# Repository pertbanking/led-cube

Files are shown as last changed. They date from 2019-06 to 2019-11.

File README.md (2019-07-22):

# led-cube
This is the repository for the code, schematics, and boards of an 8x8x8 LED cube.

## Folder hierarchy

Folder / File            | Purpose                                                          
------------------------- | ----------------------------------------------------------------
`arduino_serial_client/`  | Arduino code.
`pcb/`                    | Contains PCB schematics and boards for the multiplexing circuit. 
&nbsp;&nbsp;&nbsp;&nbsp;`/master pcb/`        | The decoder selector circuit
&nbsp;&nbsp;&nbsp;&nbsp;`/slave pcb/`         | The D Flip-Flop circuit for each row of LEDs
&nbsp;&nbsp;&nbsp;&nbsp;`/datasheets/`        | Datasheets for the ICs in the circuit
`pi/`                     | Contains all animation code. Build the project in this directory with its `CMakeLists.txt` file (see below). So named because I recommend you run this on a Raspberry Pi.
&nbsp;&nbsp;&nbsp;&nbsp;`/serial/`            | The standalone `serial` library (see below).
&nbsp;&nbsp;&nbsp;&nbsp;`/src/`               | Code source.
&nbsp;&nbsp;&nbsp;&nbsp;&nbsp;&nbsp;&nbsp;&nbsp;`/LEDCube.h`     | Represents the cube. Sends data to the Arduino through `serial`. Contains many helpful drawing functions. 
&nbsp;&nbsp;&nbsp;&nbsp;&nbsp;&nbsp;&nbsp;&nbsp;`/Animation.h`   | Header file for the generic animation. Extend this class to make your own animation!
&nbsp;&nbsp;&nbsp;&nbsp;&nbsp;&nbsp;&nbsp;&nbsp;`/animations/`   | Contains animation files. Each file represents a different animation.
&nbsp;&nbsp;&nbsp;&nbsp;&nbsp;&nbsp;&nbsp;&nbsp;`/main.cpp`      | An example client program. It is highly recommended you specialize this program instead of making your own.

More details coming soon.

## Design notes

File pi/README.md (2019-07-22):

# Animator

These classes represent the LED cube and its animations. They are meant to be run on a system (I used a Raspberry Pi) with an Arduino connected to its USB port. 

## Build

### Executable
```
$ mkdir build && cd build
$ cmake ..
$ make
```

### Documentation
```
$ doxygen
````

## Run
In the `pi` directory,
```
$ ./animate [name of the Aruduino's USB port]
```
(assuming you haven't changed the name of the executable in the CMake folder)

The default value of the USB port is `/dev/ttyUSB0`, but you may have to specify it in the command line. 

## Making your own animations
Coming soon.

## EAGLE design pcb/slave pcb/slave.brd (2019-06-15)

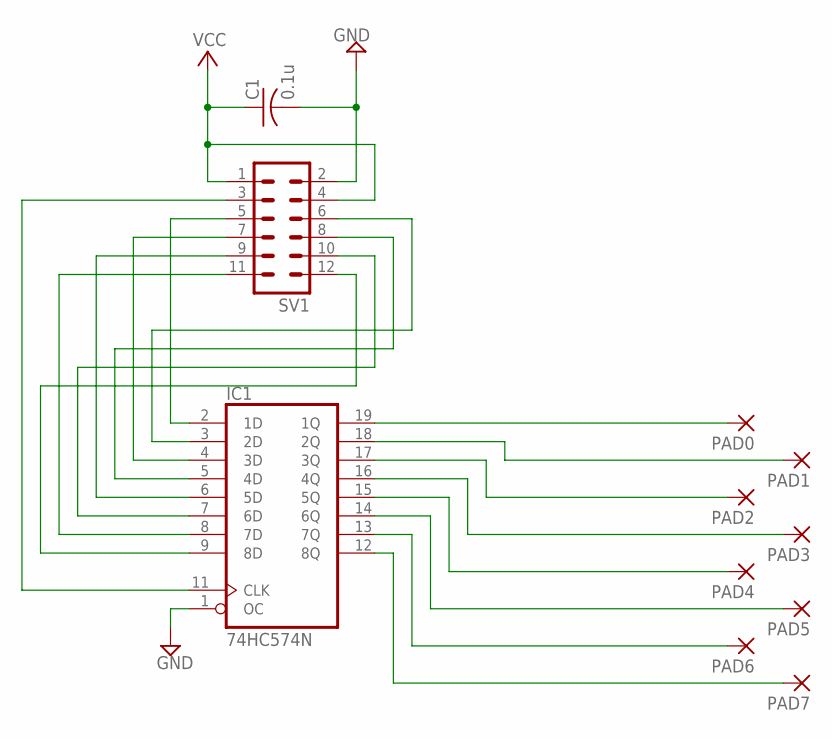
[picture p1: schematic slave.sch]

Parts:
C1: 0.1u; C0805
IC1: 74HC574N; DIL20
PAD0, PAD1, PAD2, PAD3, PAD4, PAD5, PAD6, PAD7: 2,54/0,8
SV1: MA06-2

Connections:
CLK: IC1.11 (CLK), SV1.3
GND: C1.2, IC1.1 (OC), IC1.10 (GND), SV1.2
IN0: IC1.2 (1D), SV1.5
IN1: IC1.3 (2D), SV1.6
IN2: IC1.4 (3D), SV1.7
IN3: IC1.5 (4D), SV1.8
IN4: IC1.6 (5D), SV1.9
IN5: IC1.7 (6D), SV1.10
IN6: IC1.8 (7D), SV1.11
IN7: IC1.9 (8D), SV1.12
unnamed: IC1.19 (1Q), PAD0.1
unnamed: IC1.18 (2Q), PAD1.1
unnamed: IC1.17 (3Q), PAD2.1
unnamed: IC1.16 (4Q), PAD3.1
unnamed: IC1.15 (5Q), PAD4.1
unnamed: IC1.14 (6Q), PAD5.1
unnamed: IC1.13 (7Q), PAD6.1
unnamed: IC1.12 (8Q), PAD7.1
VCC: C1.1, IC1.20 (VCC), SV1.1, SV1.4

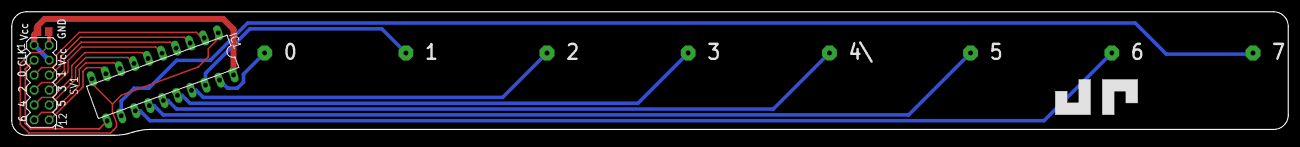
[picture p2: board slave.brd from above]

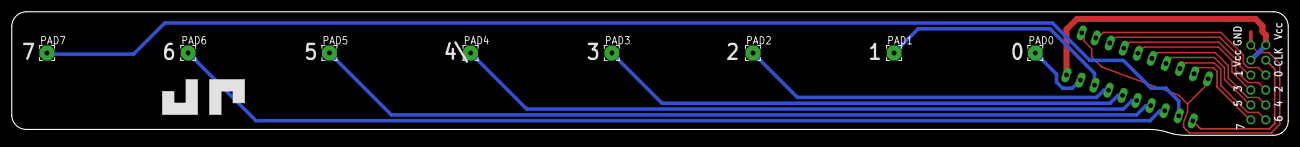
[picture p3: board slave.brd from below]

Board: 2 copper layers, 217.0 x 21.0 mm, 11 parts (8 on the bottom side), 19 nets.

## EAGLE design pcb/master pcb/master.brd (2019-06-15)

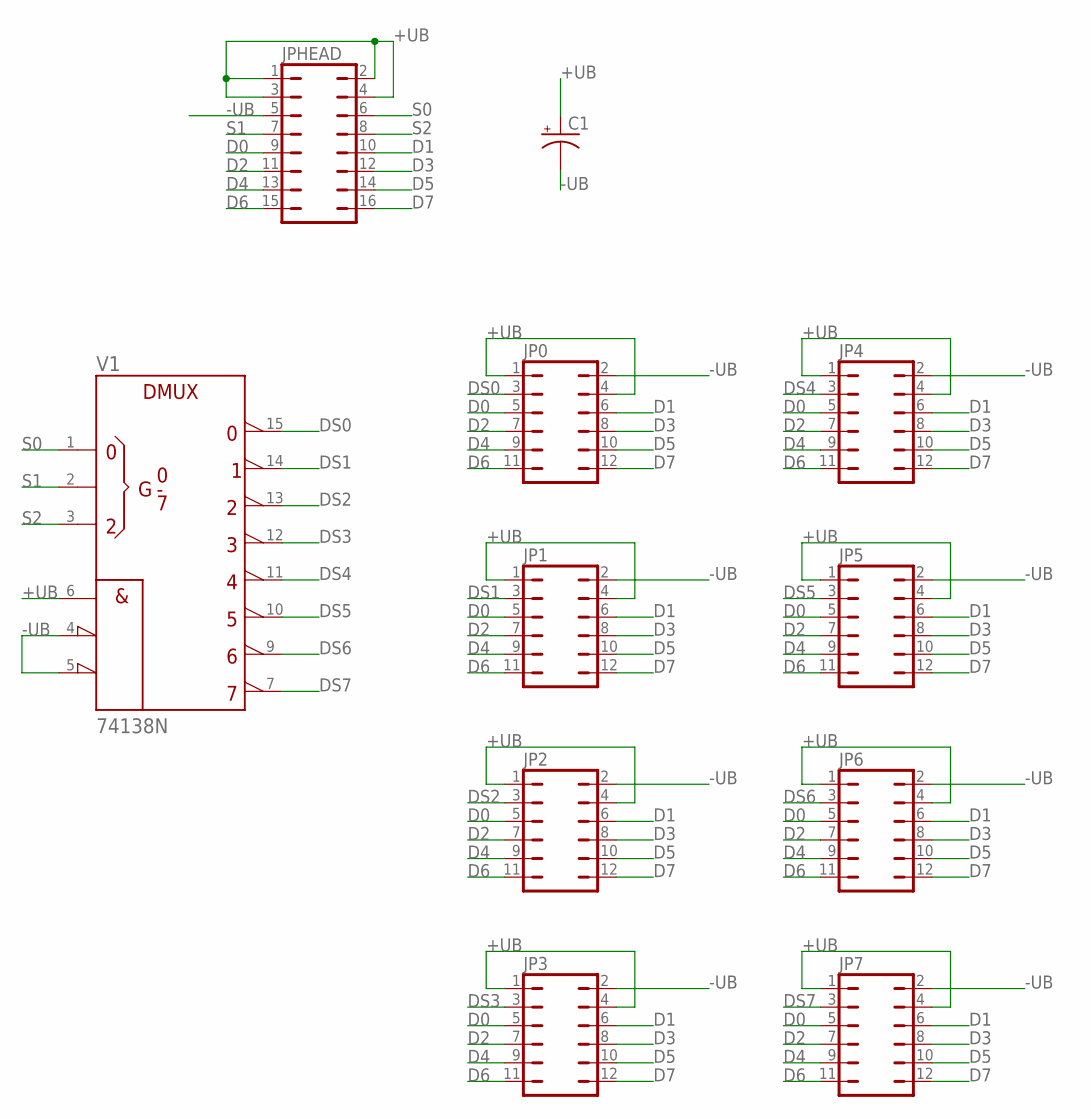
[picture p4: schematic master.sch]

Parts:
C1: CPOL-USTT2D4; TT2D4
JP0, JP1, JP2, JP3, JP4, JP5, JP6, JP7: JP6Q
JPHEAD: JP8Q
V1: 74138N; DIL16

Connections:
+UB: C1.+, JP0.1, JP0.4, JP1.1, JP1.4, JP2.1, JP2.4, JP3.1, JP3.4, JP4.1, JP4.4, JP5.1, JP5.4, JP6.1, JP6.4, JP7.1, JP7.4, JPHEAD.1, JPHEAD.2, JPHEAD.3, JPHEAD.4, V1.6 (G1), V1.16 (+UB)
-UB: C1.-, JP0.2, JP1.2, JP2.2, JP3.2, JP4.2, JP5.2, JP6.2, JP7.2, JPHEAD.5, V1.4 (!G2A), V1.5 (!G2B), V1.8 (-UB)
D0: JP0.5, JP1.5, JP2.5, JP3.5, JP4.5, JP5.5, JP6.5, JP7.5, JPHEAD.9
D1: JP0.6, JP1.6, JP2.6, JP3.6, JP4.6, JP5.6, JP6.6, JP7.6, JPHEAD.10
D2: JP0.7, JP1.7, JP2.7, JP3.7, JP4.7, JP5.7, JP6.7, JP7.7, JPHEAD.11
D3: JP0.8, JP1.8, JP2.8, JP3.8, JP4.8, JP5.8, JP6.8, JP7.8, JPHEAD.12
D4: JP0.9, JP1.9, JP2.9, JP3.9, JP4.9, JP5.9, JP6.9, JP7.9, JPHEAD.13
D5: JP0.10, JP1.10, JP2.10, JP3.10, JP4.10, JP5.10, JP6.10, JP7.10, JPHEAD.14
D6: JP0.11, JP1.11, JP2.11, JP3.11, JP4.11, JP5.11, JP6.11, JP7.11, JPHEAD.15
D7: JP0.12, JP1.12, JP2.12, JP3.12, JP4.12, JP5.12, JP6.12, JP7.12, JPHEAD.16
DS0: JP0.3, V1.15 (Y0)
DS1: JP1.3, V1.14 (Y1)
DS2: JP2.3, V1.13 (Y2)
DS3: JP3.3, V1.12 (Y3)
DS4: JP4.3, V1.11 (Y4)
DS5: JP5.3, V1.10 (Y5)
DS6: JP6.3, V1.9 (Y6)
DS7: JP7.3, V1.7 (Y7)
S0: JPHEAD.6, V1.1 (A)
S1: JPHEAD.7, V1.2 (B)
S2: JPHEAD.8, V1.3 (C)

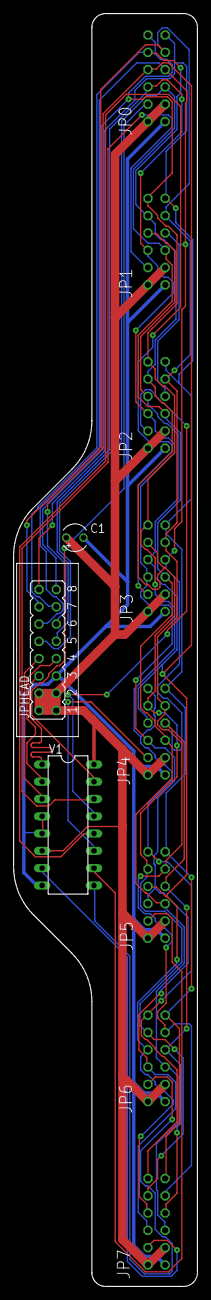
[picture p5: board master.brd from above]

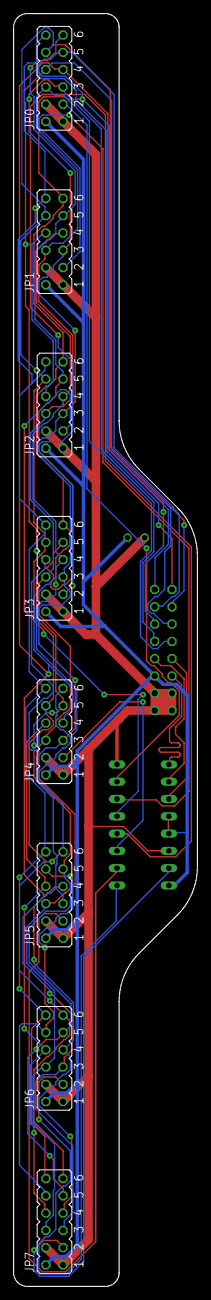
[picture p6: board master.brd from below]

Board: 2 copper layers, 27.0 x 187.0 mm, 11 parts (8 on the bottom side), 21 nets.

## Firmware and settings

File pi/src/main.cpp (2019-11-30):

/*
 * Software License Agreement:
 * do whatever teh crap you want with this software
 * just mention my name if you use it, bitte
 *
 * Author: Joshua Petrin <joshua.m.petrin@vanderbilt.edu>
 */

#include <algorithm>
#include <chrono>
#include <iostream>
#include <list>
#include <memory>
#include <random>
#include <thread>
#include <vector>
#include <cstdio>
#include <cstdint>

#include "LEDCube.h"
#include "LEDCubeUSBStreamer.h"
#include <serial/serial.h>

#include "animations/Rain.cpp"
#include "animations/PlaneWop.cpp"
#include "animations/CubeWop_I.cpp"
#include "animations/Fireworks.cpp"
#include "animations/Waves_I.cpp"
#include "animations/Waves_II.cpp"
#include "animations/FlashFade.cpp"
#include "animations/Suspension.cpp"
#include "animations/CubeConstructor.cpp"


// the cube as a bool array
bool cube[8][8][8];  // x, y, z

// how fast we calculate new frames
int fps = 60;

const std::string MAGIC_BYTES = "JANDY";  // magic bytes

// usb port pointing to the arduino
const std::string USB_PORT_DEFAULT = "/dev/ttyUSB0";
std::string usb_port = USB_PORT_DEFAULT;

// serial object, from the amazing serial package
shared_ptr<serial::Serial> usb;


void displayAnimation(Animation &ani, LEDCube* cube, int frames, int framerate) {
    while (ani.getFrame() < frames) {
        // get the current time
        auto start = std::chrono::system_clock::now();

        ani.next(cube);

        // get the current time after the frame calculation
        auto stop = std::chrono::system_clock::now();
        
        // sleeeeeep for however long the animation recommends us
        double duration = 1000000.0 / double(framerate)
            - std::chrono::duration<double, std::micro>(stop - start).count();

        std::this_thread::sleep_for(
            std::chrono::microseconds(int(duration))
        );
    }
}


int main(int argc, char* argv[]) {

    if (argc > 1) {
        usb_port = argv[1];
    }
    std::cout << "Intializing." << std::endl;
    std::this_thread::sleep_for(std::chrono::milliseconds(100));
    try {
        usb.reset(new serial::Serial(
            usb_port, // TODO: Make a program that will test the ports
            115200,
            serial::Timeout::simpleTimeout(250),
            serial::eightbits,
            serial::parity_none,
            serial::stopbits_one,
            serial::flowcontrol_none));
        usb->setDTR(true);
        usb->setRTS(true);
        std::cout << "Port '" << usb_port << "' opened successfully." << std::endl;
    }
    catch (serial::IOException& e) {
        std::cout << "Could not open port at " << usb_port << "." << std::endl;
        LEDCubeUSBStreamer::destroyInstance();
        return 1;
    }

    if (usb->isOpen()) {
        LEDCubeUSBStreamer* cube = LEDCubeUSBStreamer::getInstance(usb);

        std::cout << "Sleeping for 2 seconds..." << std::endl;
        // this sleep is essential. if the arduino receives serial signals 
        // before it initializes, it will never enter program control.
        std::this_thread::sleep_for(std::chrono::milliseconds(2000));

        // start the cube's broadcast to the usb
        cube->startBroadcast();
        std::cout << "Live." << std::endl;

        //
        //
        //
        // Begin animation declarations and displays
        //

        // The list of animations. We will just loop through these
        std::list<Animation*> animation_list;
        animation_list.push_back(new CubeConstructor());
        animation_list.push_back(new Waves_II());
        animation_list.push_back(new Suspension());
        animation_list.push_back(new FlashFade());
        animation_list.push_back(new CubeWop_I());
        animation_list.push_back(new Waves_I());
        animation_list.push_back(new Fireworks());
        animation_list.push_back(new Rain());
        animation_list.push_back(new PlaneWop());

        // simpley repeeat untiel wee waent toe stoep
        int repeats = 1000;

        while (repeats) {
            for (Animation* ani : animation_list) {
                std::cout << "Starting animation " 
                          << ani->getName() 
                          << "." 
                          << std::endl;

                displayAnimation( // force this thread to display the animation
                    *ani,         // in real-time
                    cube, 
                    ani->getRecommendedDuration(), 
                    ani->getRecommendedFramerate());

                // reset the animation so we don't have to make a new object
                ani->reset();
            }

            // repeat
            --repeats;
        }

        // clean up the cube instance
        std::cout << "Destroying LEDCube instance..." << std::endl;
        LEDCubeUSBStreamer::destroyInstance();
        std::cout << "Done." << std::endl;
        return 0;
        // all in a day's work
    }
}

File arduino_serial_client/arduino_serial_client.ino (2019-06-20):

#define LAYERS_OFF() PORTL = 0;
#define SET_LAYER(layer) PORTL = 1 << layer;
#define SET_TARGET_REG(reg) PORTA = reg & 0b00000111;
#define SET_REG_VALS(vals) PORTC = vals & 0b11111111;

const char* MAGIC_BYTES = "JANDY";  // the magic bytes at the beginning of a cube frame
                                    // yes, this is an inside joke.

unsigned char buffer0[64]; // the data for the current frame of the cube
                                    // 8x8x8: an 8x8 square of 8-bit chars
unsigned char buffer1[64]; // we use two buffers: one for displaying, and 
                                    // one for filling with values from serial.
unsigned char* cube = buffer0; // we set this pointer to whatever is the current cube
unsigned char* store = buffer1;// set this one to the next cube
bool bufferswitch = false; // false => cube is at buffer0, true => buffer1

void setup() {
  // pins 22-24 (PA0-PA2) are for the decoder inputs
  // pins 37-30 (PC0-PC7) are the data bits for each row, and 
  // pins 49-42 (PL0-PL7) are the layer selector bits
  for (int i = 22; i <= 49; ++i) {
    pinMode(i, OUTPUT);
    if (i == 24)
      i = 29;
    if (i == 37)
      i = 41;
  }
  
  LAYERS_OFF();
  
  for (int i = 0; i < 64; ++i) {
    cube[i] = 0x00;
  }
  
  Serial.begin(115200);
}

bool receiving = false;
int magic = 0;  // number of magic bytes traversed.
int cube_ref = 0;  // the reference for the input cube byte stream

void loop() {
  if (Serial.available() > 0) {
    char bittyboi = Serial.read();
    if (!receiving) {
      if (bittyboi == MAGIC_BYTES[magic])  // next magic byte received!
        ++magic;
      else
        magic = 0;
      if (magic == 5) {  // all bytes received
        receiving = true;
        magic = 0;
      }
    } else {
      // set 'store' to the values we receive
      store[cube_ref] = bittyboi;
      ++cube_ref;
      if (cube_ref > 63) {
        // switch the references
        if (bufferswitch) {
          store = buffer1;
          cube = buffer0;
          bufferswitch = false;
        } else {
          store = buffer0;
          cube = buffer1;
          bufferswitch = true;
        }
        cube_ref = 0;
        receiving = false;
      }
    }
  }
  
//    __asm("nop\nnop\nnop\nnop\nnop\nnop\nnop\nnop\nnop\nnop\nnop\nnop\nnop\nnop\nnop\nnop\n"
//    "nop\nnop\nnop\nnop\nnop\nnop\nnop\nnop\nnop\nnop\nnop\nnop\nnop\nnop\nnop\nnop\nnop\nnop\n"
//    "nop\nnop\nnop\nnop\nnop\nnop\nnop\nnop\nnop\nnop\nnop\nnop\nnop\nnop\nnop\nnop\nnop\nnop\n");
  
  for (int i = 0; i < 8; ++i) {
    SET_REG_VALS(cube[8*i]);
    SET_TARGET_REG(1);
    SET_REG_VALS(cube[8*i+1]);
    SET_TARGET_REG(2);
    SET_REG_VALS(cube[8*i+2]);
    SET_TARGET_REG(3);
    SET_REG_VALS(cube[8*i+3]);
    SET_TARGET_REG(4);
    SET_REG_VALS(cube[8*i+4]);
    SET_TARGET_REG(5);
    SET_REG_VALS(cube[8*i+5]);
    SET_TARGET_REG(6);
    SET_REG_VALS(cube[8*i+6]);
    SET_TARGET_REG(7);
    SET_REG_VALS(cube[8*i+7]);
    SET_TARGET_REG(0);
    
    
    SET_LAYER(i);  // turn the layer on and let the lights flash for a second
    
    // the number of nop's here determines the brightness of the cube
    __asm("nop\nnop\nnop\nnop\nnop\nnop\nnop\nnop\nnop\nnop\nnop\nnop\nnop\nnop\nnop\nnop\n"
    "nop\nnop\nnop\nnop\nnop\nnop\nnop\nnop\nnop\nnop\nnop\nnop\nnop\nnop\nnop\nnop\nnop\nnop\n"
    "nop\nnop\nnop\nnop\nnop\nnop\nnop\nnop\nnop\nnop\nnop\nnop\nnop\nnop\nnop\nnop\nnop\nnop\n"
    "nop\nnop\nnop\nnop\nnop\nnop\nnop\nnop\nnop\nnop\nnop\nnop\nnop\nnop\nnop\nnop\nnop\nnop\n"
    "nop\nnop\nnop\nnop\nnop\nnop\nnop\nnop\nnop\nnop\nnop\nnop\nnop\nnop\n");
    
    LAYERS_OFF();
    
  }
  
}

// JANDY?99?00009009000090090000?99?000000000000000000000000000000000000
// JANDY0000000000000000000000000000000000000000000000000000000000000000

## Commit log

2019-01-12 Created slave board schematic and layout
    [slave.brd, slave.sch]
2019-01-12 changed mah logo
    [slave.brd]
2019-06-15 final version prototype
    [master.brd, master.sch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]
2019-06-30 organized some stuff
    [master.brd, master.sch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]
2019-07-13 didn't like the name :/
    [LEDCube.cpp, LEDCube.h]
2019-07-23 reference #3: LEDCube has been virtualized (i.e. it has no virtual methods but you can't make an instance of it anymore) + LEDCubeUSBStreamer class
2019-12-06 forced all frames to go to 0 on the reset() call
